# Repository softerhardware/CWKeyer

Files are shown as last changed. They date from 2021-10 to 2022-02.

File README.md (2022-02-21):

# CW Keyer for the Hermes-Lite and other SDR software

This project is a CW keyer for amateur radio. The hardware connects to a PC with USB. It then appears as an audio device for radio sound output and microphone input. It is also a Midi device to signal key up/down to the PC software, and a serial device for a connection to logging or other software on the PC. It is designed for the [Hermes-Lite 2.0](http://www.hermeslite.com/) or other SDR software. The radio sound is sent to the keyer and the keyer generates a sidetone, mixes it with the audio and sends it to the headphones or speaker. The sidetone has zero delay and is suitable for high speed CW. The keyer can also be used with a regular analog radio by using the key and PTT outputs. This project is currently a DIY project with instructions below for those who feel comfortable with some light soldering and Arduino programming.

## Hardware

The hardware consists of a carrier board as shown below and a [Teensy 4](https://www.pjrc.com/teensy/) microcontroller.
The Teensy can be purchased from [Teensy](https://www.pjrc.com/store/teensy40.html) or from [sparkfun](https://www.sparkfun.com/), [adafruit](https://www.adafruit.com/), [mouser](https://www.mouser.com/), [digikey](https://www.digikey.com/) or [amazon](https://www.amazon.com/). Make sure to order the Teensy 4.

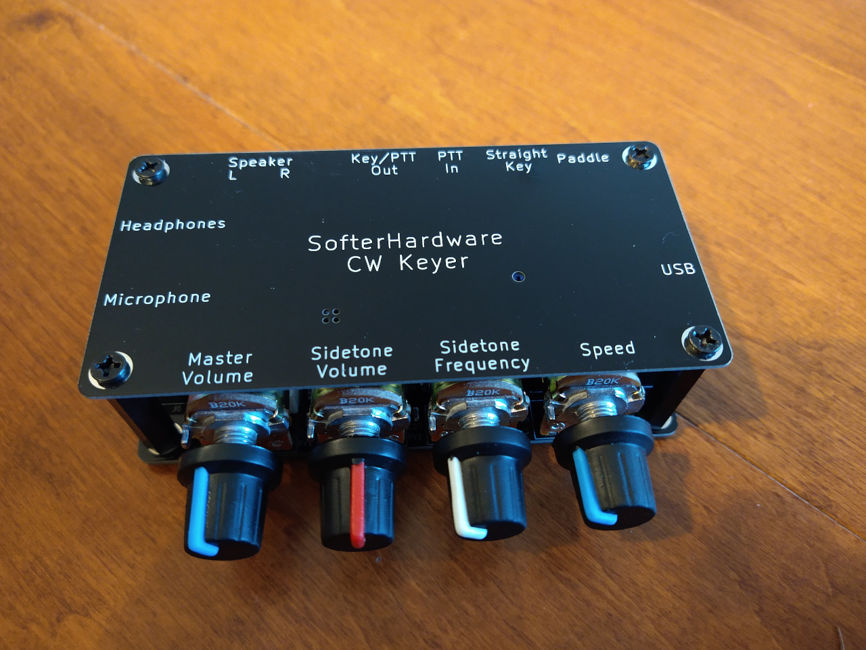
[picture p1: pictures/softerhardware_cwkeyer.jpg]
SofterHardwareCWKeyer


## Software

Keyer software must be loaded into the Teensy 4 microcontroller. The Teensy 4 is programmed via a usb connection to a host computer. First, download and install the Teensy loader application for your operating system as described on [this page](https://www.pjrc.com/teensy/loader.html). Then start the teensy application. Press the programming button on the Teensy and the teensy app will change to show a picture of the board. Then select the ".hex" program file, select "program" and then "reboot".

There are currently two keyer programs available, the "hasak" and the "TeensyWinkeyEmulator". Click on the "firmware" link above, and click through the directories until you find the hex file you want. The file will appear as a table of numbers with a "Raw" button on the upper right side. Right click the Raw button and select "Save link as". Make sure the file name ends in ".hex". Save the hex file and use it to program the Teensy.

## Ctrlr

TBD: Basic description, download and use instructions for Ctrlr MIDI control panel.

## Software Development

To write your own keyer software or to contribute to software development first clone this repository.
This git repository uses several submodules to collect various projects into a single repository. You must initialize submodules when intially cloning:

git clone --recurse-submodules git@github.com:softerhardware/CWKeyer.git

After that, also be sure to pull updates from submodules:

git pull --recurse-submodules

You can find more details about how to work with git submodules on the internet.

### Teensy Libraries

Current development is done using [Arduino IDE 1.8.19](https://www.arduino.cc/en/software) and [Teensyduino 1.56](https://www.pjrc.com/teensy/td_download.html). Please make sure those are installed.

Updated libraries are required for glitchless 48kHz audio with the CW keyer hardware. These libraries are provided in this git repository. An easy way to use these libraries is to add symbolic links to the new libraries from the arduino IDE install. This is described below for Linux and MacOS systems.

Be sure to select the "Teensy 4.0" board in the Tools-->Boards-->Teensiduino menu, and to select the "Serial + Midi + Audio" USB model in the Tools-->USB type menu,
otherwise compilation will fail.

Install teensy  library update for linux:
-----------------------------------------

 1. cd arduino-1.8.19/hardware/teensy/avr
 2. rm -rf cores   (This must be removed or moved outside of the arduino-1.8.19 area otherwise arduino will still pickup this code)
 3. ln -s /home/shaynal/CWKeyer/libraries/teensy/cores .   (Substitute the path for your local git pull of the CWKeyer repository)
 4. cd libraries
 5. rm -rf Audio   (See step 2 comments)
 6. ln -s /home/shaynal/CWKeyer/libraries/teensy/Audio .   (See step 3 comments)
 7. ln -s /home/shaynal/CWKeyer/libraries/teensy/CWKeyerShield .   (See step 3 comments)

Install teensy library update for MacOS:
----------------------------------------

(Added by DL1YCF. Note this is best done from the "terminal" app, then this is very similar to the
linux case).

All the libraries are inside the Teensyduino "app" file bundle (which is a directory tree)
/Applications/Teensyduino.app. Locate a sub-folder called "Audio", this will point you to
the libraries for the Teensy. Normally this is located in

/Applications/Teensyduino.app/Contents/Java/hardware/teensy/avr/libraries

You can copy the "Audio" folder within that folder to a safe place (or just delete it),
and do the same to the "cores" folder one step higher, that is, the "cores" folder within

/Applications/Teensyduino.app/Contents/Java/hardware/teensy/avr

Then proceed as in the linux case, that is, add a symbolic link named "cores" in the .../teensy/avr
folder and two symbolic links called "Audio" and "CWKeyerShield" in the
.../teensy/avr/libraries folder, that point to the directories "Audio", "cores" and
"CWKeyerShield" where you have placed them after down-loading from this repository.

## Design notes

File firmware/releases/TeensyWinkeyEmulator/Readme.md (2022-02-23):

Releases/TeensyWinkeyEmulator
=============================

This directory contains two pre-compiled versions of the TeensyWinkeyEmulator,
one running with the "KeyerShield" (featuring a WM8960 audio codec), the other
for a "SGTL5000 prototype" that is a Teensy 4.0 attached to the "official"
Teensy4 AudioShield (that has a SGTL-5000 codec).

The "prototype" is "keyer only", that is, no Microphone/PTT input, and only
a single potentiometer for changing the CW speed. It has inputs for straight
key and paddle, and an output for the headphone.

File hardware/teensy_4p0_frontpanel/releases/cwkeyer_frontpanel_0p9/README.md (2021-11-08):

CW Keyer Front Panel 0.9 Release
====================

November 7, 2021. This directory contains all files necessary to fabricate the SofterHardware CW Keyer front panel for the Teensy 4.0.

# Files

 * pcb/* - Gerber files names as requested by assembly house

# Changes

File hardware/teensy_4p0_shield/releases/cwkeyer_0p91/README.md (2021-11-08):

CW Keyer 0.9 Release
====================

November 7, 2021. This directory contains all files necessary to fabricate the SofterHardware CW Keyer shield for the Teensy 4.0.

# Files

 * bom/ibom.html - Interactive BOM to help with DIY assembly, open with "firefox ibom.html"
 * cwkeyer.xlsx - BOM type and organization as requested by assembly house
 * cwkeyer.pdf - Schematic for this release
 * pcb/* - Gerber files names as requested by assembly house
 * position/* - Position information to aid assembly, not guaranteed to be accurate for parts with more than two pins
 * stencil/* - Top and bottom stencils for stencil creation guidance

# Changes

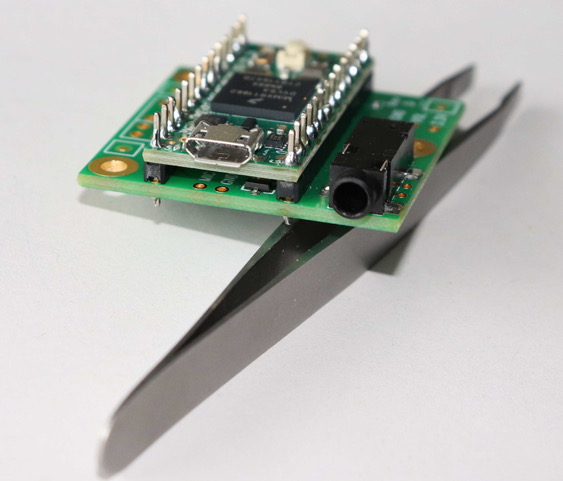
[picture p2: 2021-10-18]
pictures/dl1ycf.jpg

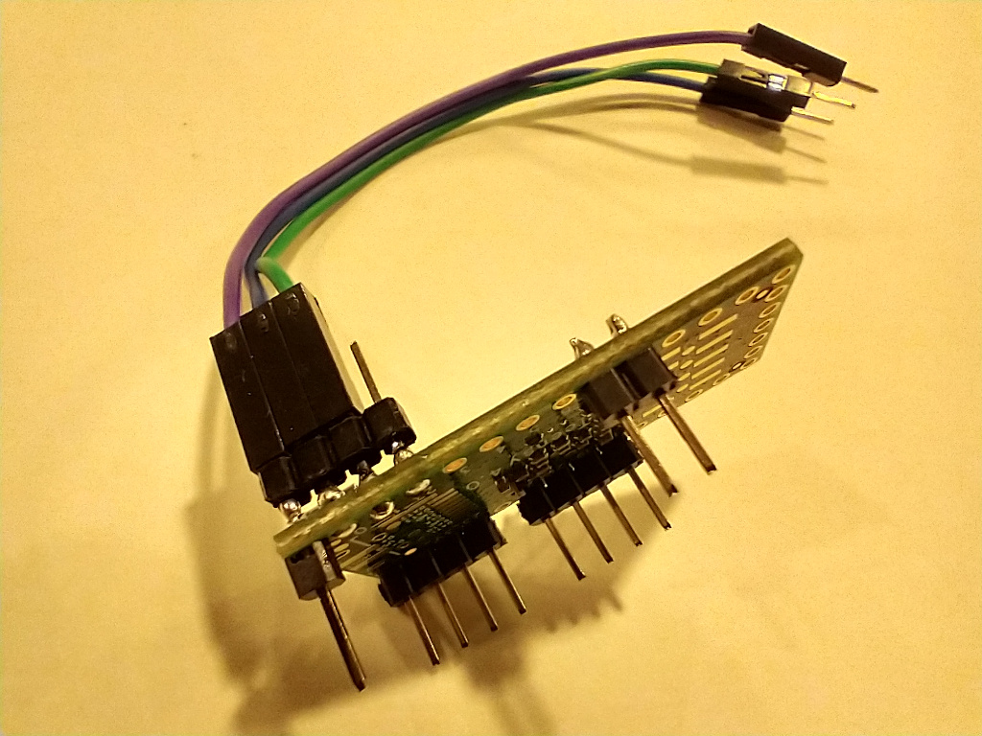
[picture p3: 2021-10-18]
pictures/teensy4.jpg

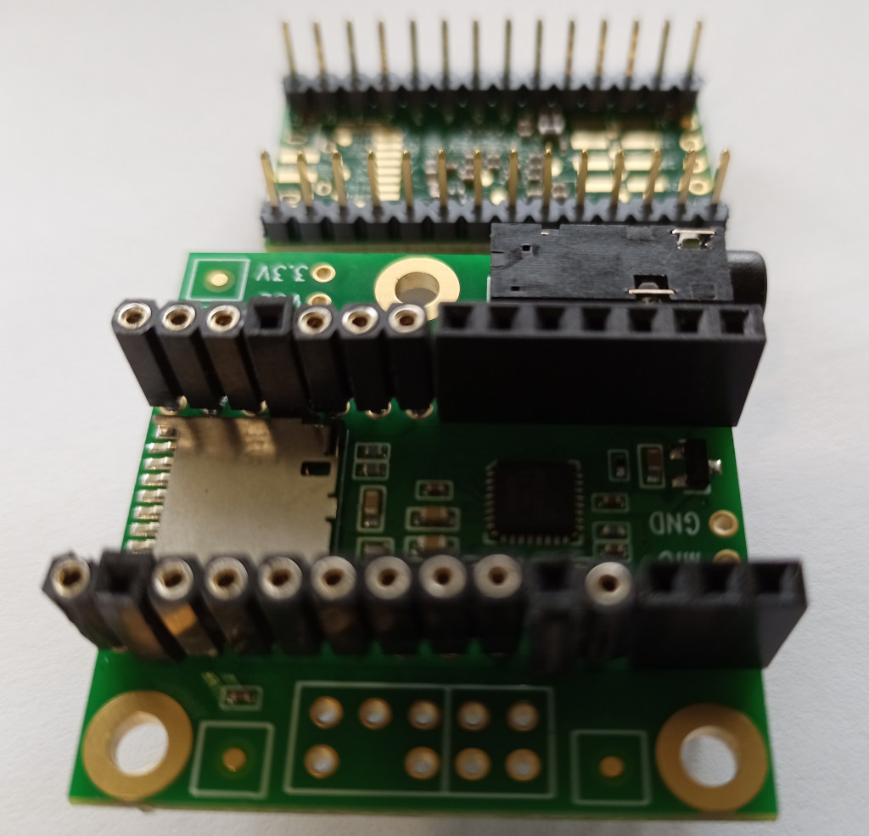
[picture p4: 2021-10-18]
pictures/Shield_Top.jpg

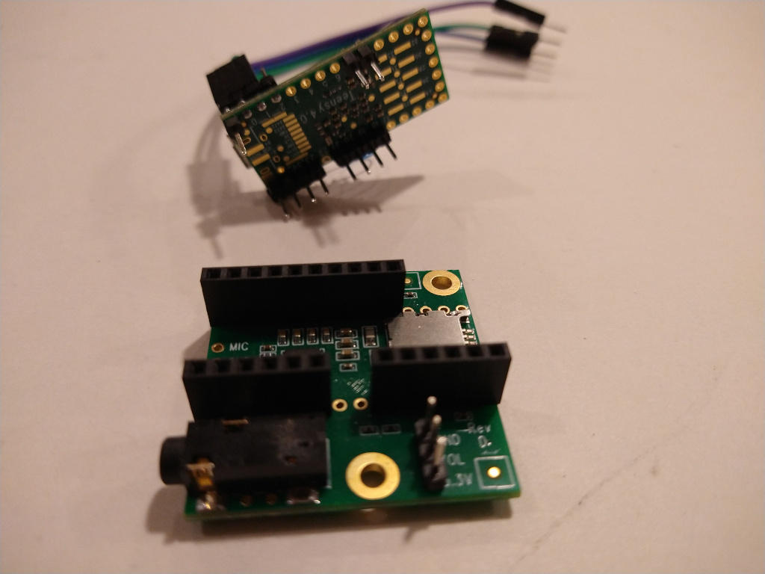
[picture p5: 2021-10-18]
pictures/audioshield.jpg

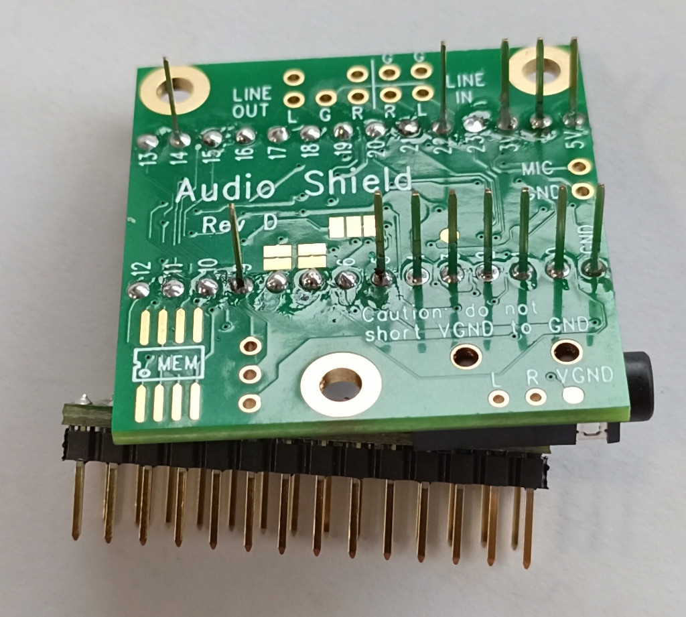
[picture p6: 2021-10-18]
pictures/Shield_Under.jpg

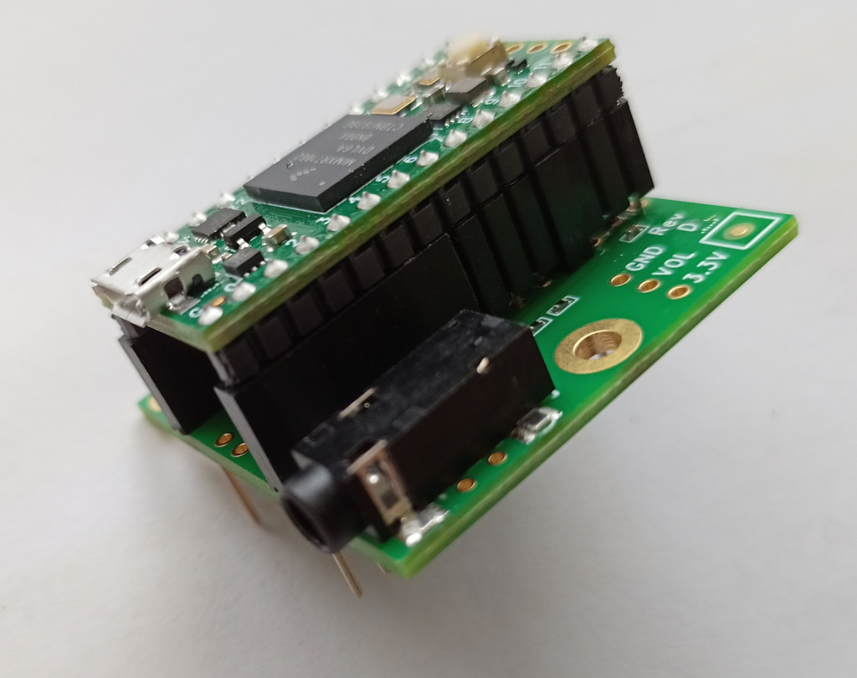
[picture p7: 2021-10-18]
pictures/Plugged_together.jpg

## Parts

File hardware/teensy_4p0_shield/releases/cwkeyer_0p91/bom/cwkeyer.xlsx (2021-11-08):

Line | Designators | Value | Specification | Footprint | Substitution Allowed | LCSC | Quantity | SMT Pins | TH Pins | Notes
1 | C1, C6, C7, C8, C12, C22, C34 | 47uF | >=10V >=X5R <=20% | 1206 | Y | C96123 | 7 | 14
2 | C2, C3, C4, C5, C10, C25, C26, C27, C28, C33, C35 | 0.1uF | >=25V >=X5R <=20% | 603 | Y | C14663 | 11 | 22
3 | C9, C11, C15 | 1uF | >=25V >=X5R <=20% | 603 | Y | C15849 | 3 | 6
4 | C13, C14, C18, C19, C20, C21, C23, C24, C36, C37, C38, C39 | 33pF | >=25V >=X5R <=20% | 603 | Y | C1663 | 12 | 24
5 | C16, C17 | 470nF | >=25V >=X5R <=20% | 603 | Y | C1623 | 2 | 4
6 | C29, C30, C31, C32 | 10nF | >=25V >=X5R <=20% | 603 | Y | C57112 | 4 | 8
7 | D1 | SP0503BAHTG | TVS Diode | SOT-143 | N | C2682275 | 1 | 2
8 | FB1, FB2, FB3, FB4, FB5, FB6, FB7, FB8, FB10, FB11, FB12, FB13 | Ferrite Bead | >=500mA >=100Ohm@100MHz <=200mOhm@DC | 603 | Y | C76892 | 12 | 24
9 | J1, J2, J3, J4 | 2.5mm 2x1 Male | XH-2A |  | Y | C20079 | 4 |  | 8
10 | J5, J6, J7, J8, J9, J12 | Stereo Audio Jack | PJ-307C |  | Y | C16684 | 6 |  | 30
11 | J10 | 2.0mm 4x1 Male | PH-4A |  | Y | C2321 | 1 |  | 4
12 | J11 | 2.54mm 2x5 Male | 2.54mm common header |  | Y | C492422 | 1 |  | 10
13 | JP1 | 2.54mm 2x3 Male | 2.54mm common header |  | Y | C65114 | 1 |  | 6
14 | L1, L2, L3, L4 | 15uH | >=600mA <=600mOhm <=20% | 1210 | Y | C883545 | 4 | 8
15 | L5 | BLM18BD252SN1 | >=150mA >=2.5K@100MHz <=1.5Ohm@DC | 603 | Y | C77668 | 1 | 2
16 | MIC1 | 5A0-3729-M-42-008 | MEMS Microphone |  | N |  | 1 | 4 |  | Seeed Studio Shenzhen Guang Ji Xing Electronic Co
17 | R1, R2 | 4.7K | 1/10W <=5% | 603 | Y | C23162 | 2 | 4
18 | R3, R6, R7 | 47K | 1/10W <=5% | 603 | Y | C25819 | 3 | 6
19 | R4 | 33Ohm | 1/10W <=5% | 603 | Y | C23140 | 1 | 2
20 | R5 | 680Ohm | 1/10W <=5% | 603 | Y | C23228 | 1 | 2
21 | R10, R11, R14 | 470Ohm | 1/10W <=5% | 603 | Y | C23179 | 3 | 6
22 | RV1, RV2, RV3, RV4 | 20K Linear Taper Pot | 15mm shaft, 3 pin 5mm spacing |  | Y |  | 4 |  | 12 | https://www.aliexpress.com/item/1005002229102727.html
23 | U1 | WM8960 | Audio Codec | QFN-32 | N | C18752 | 1 | 32
24 | U2 | MOCD217R2M | OptoCoupler | SO-8_3.9mm | N | C14315 | 1 | 8
25 | U3 | 2.54mm 1x14 Socket | 2044-1X14G00SA |  | Y |  | 2 |  | 28 | Install two female sockets User to install Teensy 4.0 Digi-Key similar part 2553-2044-1X14G00SA-ND
 |  |  |  |  |  |  | 89 | 178 | 98 | Totals
Do Not Assemble:
R8, R9, R12, R13

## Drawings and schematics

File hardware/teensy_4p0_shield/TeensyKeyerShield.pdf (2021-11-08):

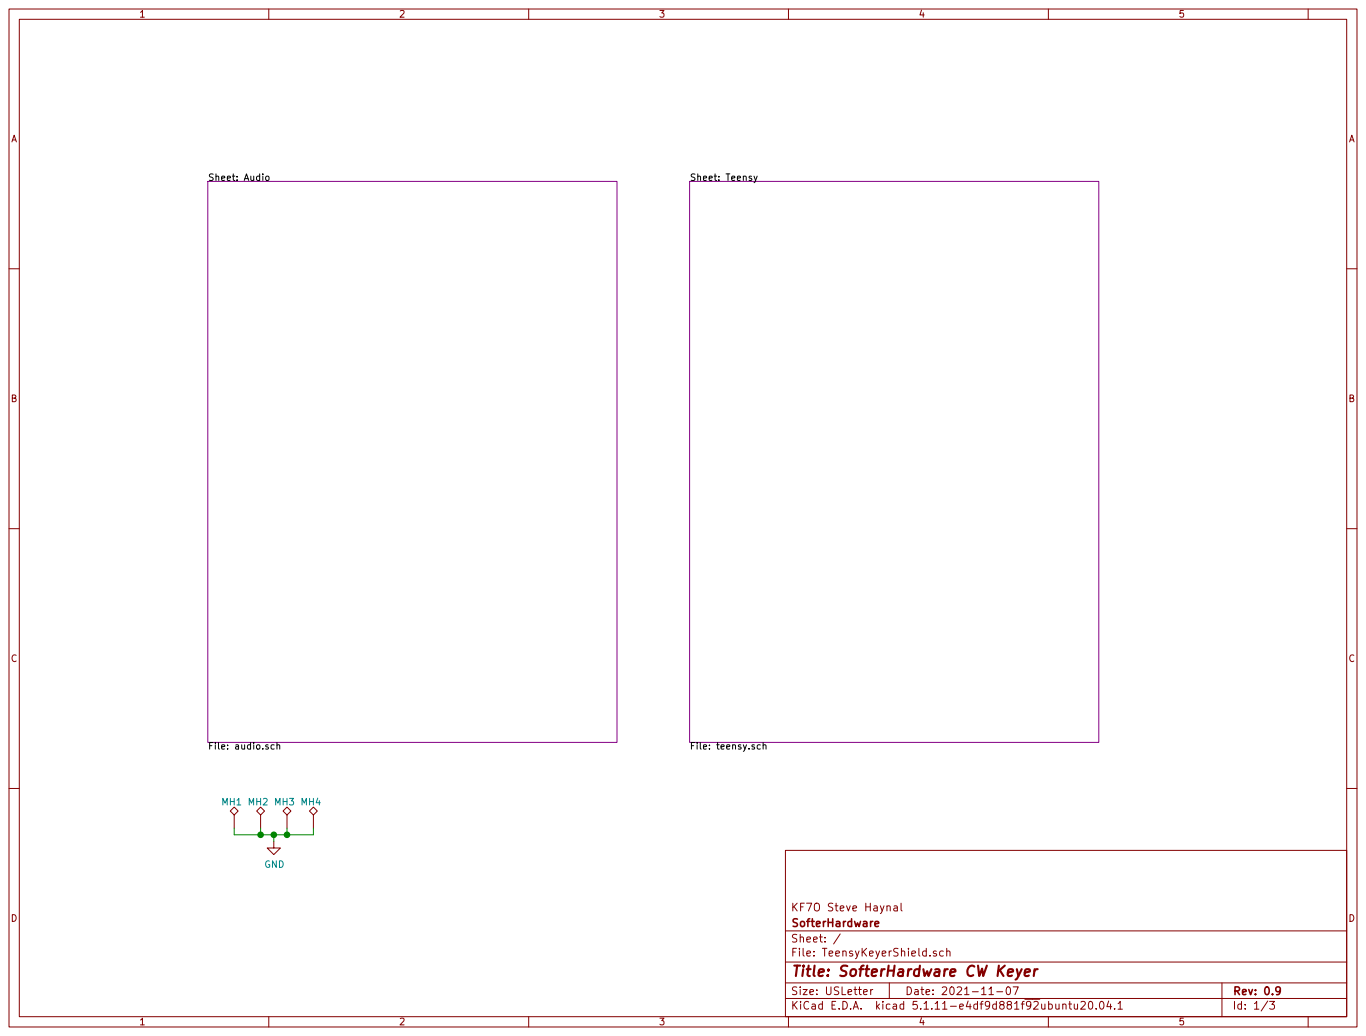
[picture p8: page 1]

Sheet: Audio File: audio.sch MH1 MH2 MH3 MH4 GND

File: TeensyKeyerShield.sch Sheet: / SofterHardware KF7O Steve Haynal

Id: 1/3 Title: SofterHardware CW Keyer

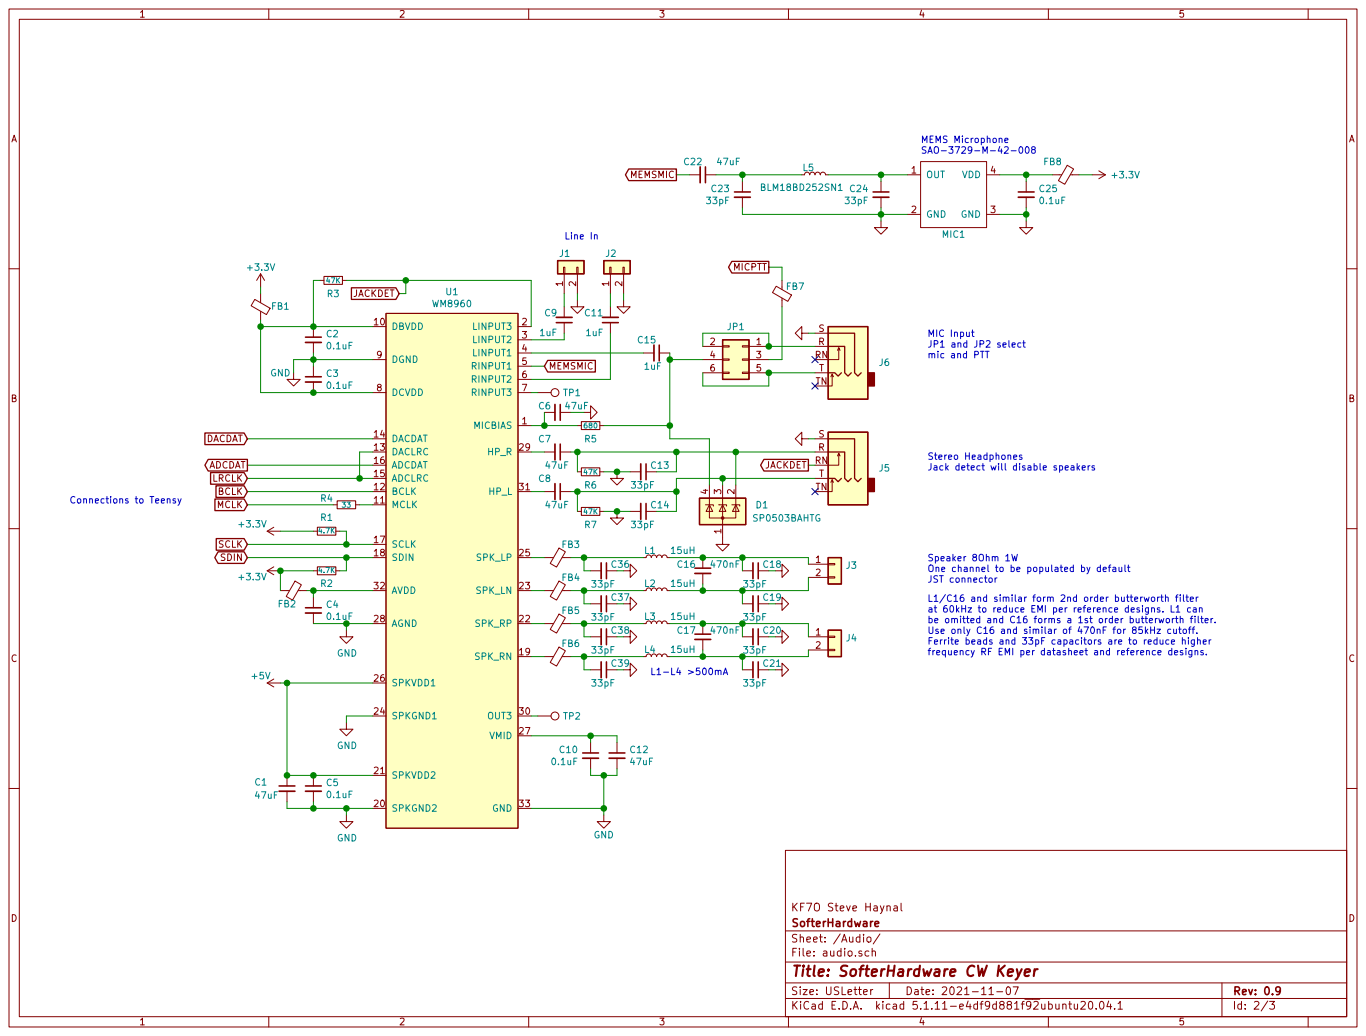
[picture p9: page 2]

MIC Input JP1 and JP2 select mic and PTT MEMS Microphone SAO-3729-M-42-008

One channel to be populated by default JST connector Stereo Headphones
Jack detect will disable speakers

L1/C16 and similar form 2nd order butterworth filter at 60kHz to reduce EMI per reference designs. L1 can

be omitted and C16 forms a 1st order butterworth filter. Use only C16 and similar of 470nF for 85kHz cutoff.

Ferrite beads and 33pF capacitors are to reduce higher
frequency RF EMI per datasheet and reference designs.

Id: 2/3 Title: SofterHardware CW Keyer File: audio.sch Sheet: /Audio/ SofterHardware KF7O Steve Haynal

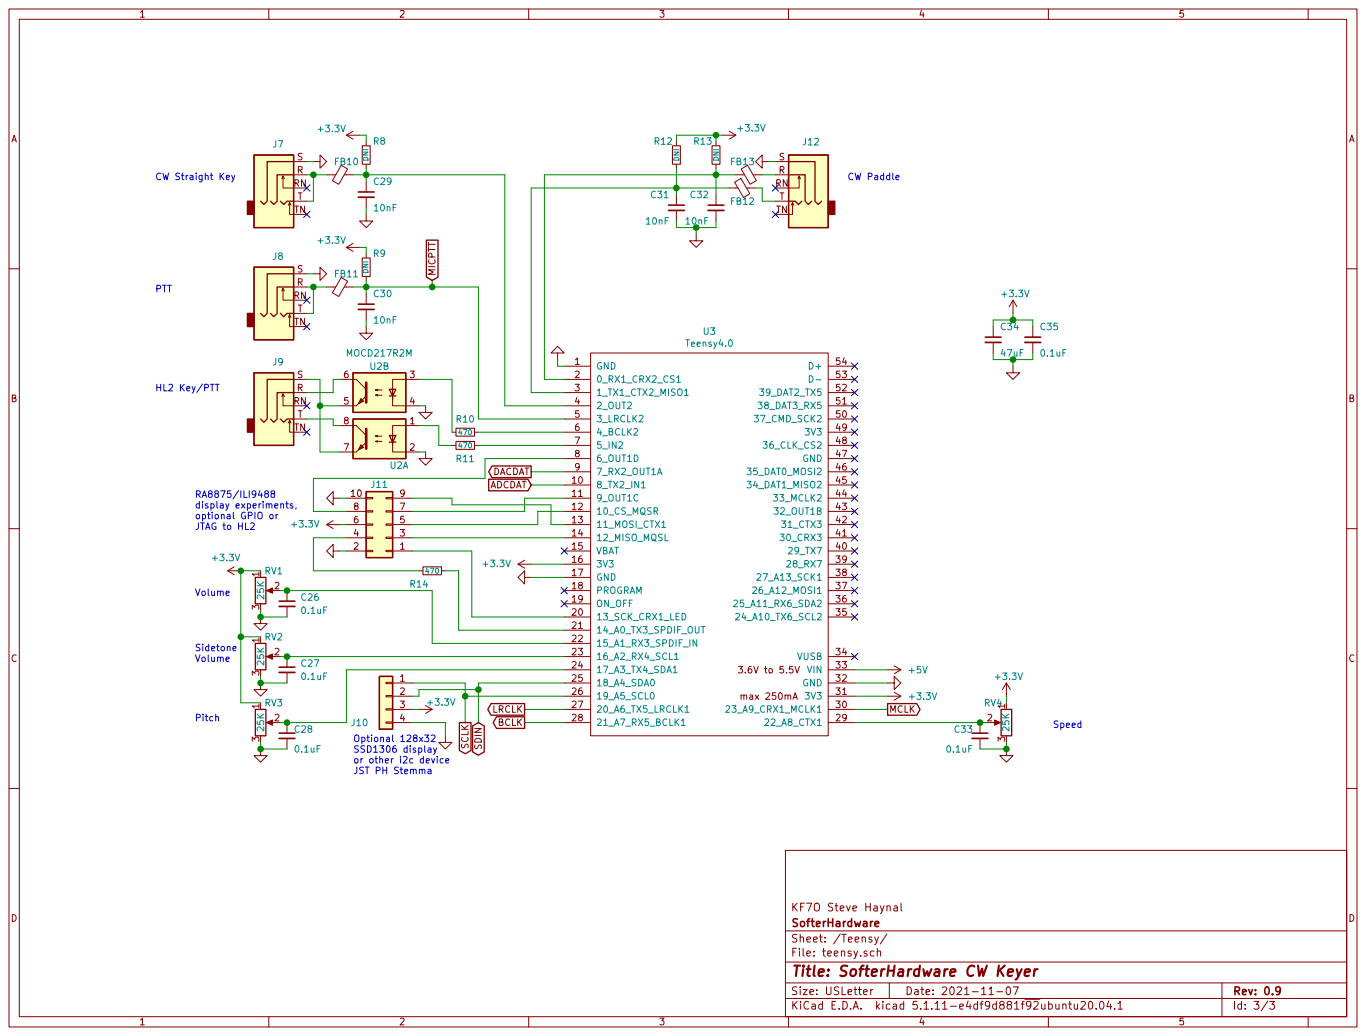
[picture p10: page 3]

JST PH Stemma RA8875/ILI9488
display experiments,
optional GPIO or JTAG to HL2

18_A4_SDA0 25

20_A6_TX5_LRCLK1 27

Optional 128x32
SSD1306 display or other i2c device

Sheet: /Teensy/ SofterHardware KF7O Steve Haynal

File: teensy.sch
Id: 3/3 Title: SofterHardware CW Keyer

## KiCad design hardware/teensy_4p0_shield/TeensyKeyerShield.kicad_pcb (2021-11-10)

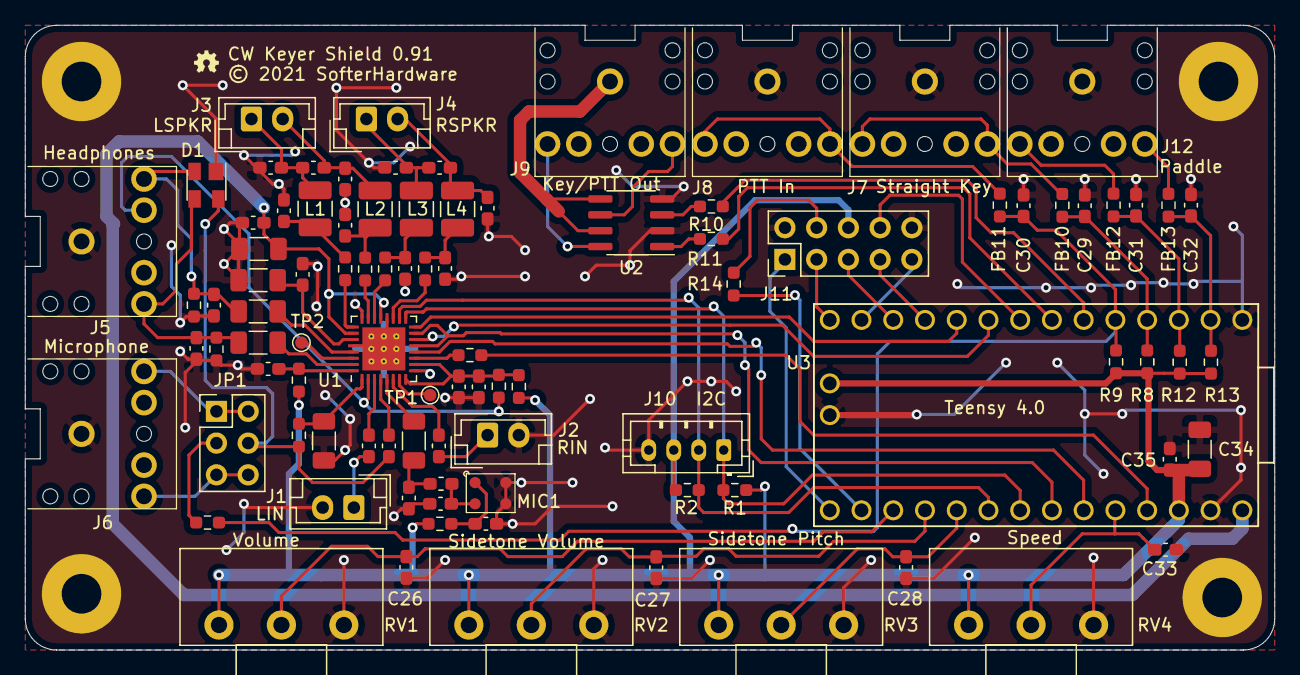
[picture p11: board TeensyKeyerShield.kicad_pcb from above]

Board: 2 copper layers, 100.0 x 50.0 mm, 98 parts (0 on the bottom side), 74 nets.

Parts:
C1, C6, C7, C8, C12, C22, C34: 47uF; C_1206_3216Metric_Pad1.33x1.80mm_HandSolder
C2, C3, C4, C5, C10, C25, C26, C27, C28, C33, C35: 0.1uF; C_0603_1608Metric_Pad1.08x0.95mm_HandSolder
C9, C11, C15: 1uF; C_0603_1608Metric_Pad1.08x0.95mm_HandSolder
C13, C14, C18, C19, C20, C21, C23, C24, C36, C37, C38, C39: 33pF; C_0603_1608Metric_Pad1.08x0.95mm_HandSolder
C16, C17: 470nF; C_0603_1608Metric_Pad1.08x0.95mm_HandSolder
C29, C30, C31, C32: 10nF; C_0603_1608Metric_Pad1.08x0.95mm_HandSolder
D1: SP0503BAHTG; SOT-143
FB1, FB2, FB3, FB4, FB5, FB6, FB7, FB8, FB10, FB11, FB12, FB13: Ferrite_Bead_Small; R_0603_1608Metric_Pad0.98x0.95mm_HandSolder
J1, J2, J3, J4: Conn_01x02; JST_EH_B2B-EH-A_1x02_P2.50mm_Vertical
J5, J6, J7, J8, J9, J12: AudioJack3_SwitchTR; STEREO_TRS
J10: Conn_01x04; JST_PH_B4B-PH-K_1x04_P2.00mm_Vertical
J11: Conn_02x05_Odd_Even; PinHeader_2x05_P2.54mm_Vertical
JP1: Conn_02x03_Odd_Even; PinHeader_2x03_P2.54mm_Vertical
L1, L2, L3, L4: 15uH; L_1210_3225Metric_Pad1.42x2.65mm_HandSolder
L5: BLM18BD252SN1; L_0603_1608Metric_Pad1.05x0.95mm_HandSolder
MH1, MH2, MH3, MH4: TestPoint_Alt; MH
MIC1: MEMSMIC
R1, R2: 4.7K; R_0603_1608Metric_Pad0.98x0.95mm_HandSolder
R3, R6, R7: 47K; R_0603_1608Metric_Pad0.98x0.95mm_HandSolder
R4: 33; R_0603_1608Metric_Pad0.98x0.95mm_HandSolder
R5: 680; R_0603_1608Metric_Pad0.98x0.95mm_HandSolder
R8, R9, R12, R13: DNI; R_0603_1608Metric_Pad0.98x0.95mm_HandSolder
R10, R11, R14: 470; R_0603_1608Metric_Pad0.98x0.95mm_HandSolder
RV1, RV2, RV3, RV4: 25K; Potentiometer_Piher_T-16H_Single_Horizontal
TP1, TP2: TestPoint; TestPoint_Pad_D1.0mm
U1: WM8960; QFN-32-1EP_5x5mm_P0.5mm_EP3.45x3.45mm_ThermalVias
U2: MOCD217R2M; SOIC-8_3.9x4.9mm_P1.27mm
U3: Teensy4.0; Teensy40

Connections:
+3V3: C34.1, C35.1, FB1.2, FB2.2, FB8.1, J10.3, J11.6, R1.1, R2.1, R8.2, R9.2, R12.2, R13.2, RV1.1, RV2.1, RV3.1, RV4.1, U3.16, U3.31
+5V: C1.1, C5.1, U1.21, U1.26, U3.33
ADCDAT: U1.16, U3.10
BCLK: U1.12, U3.28
DACDAT: U1.14, U3.9
GND: C1.2, C2.2, C3.1, C4.2, C5.2, C6.1, C10.2, C12.2, C13.2, C14.2, C18.1, C19.1, C20.1, C21.1, C23.2, C24.2, C25.2, C26.2, C27.2, C28.2, C29.2, C30.2, C31.2, C32.2, C33.2, C34.2, C35.2, C36.1, C37.1, C38.1, C39.1, D1.1, J1.2, J2.2, J5.S, J6.S, J7.S, J8.S, J10.4, J11.2, J11.10, J12.S, MH1.1, MH2.1, MH3.1, MH4.1, MIC1.2, MIC1.3, R6.1, R7.1, RV1.3, RV2.3, RV3.3, RV4.3, U1.9, U1.20, U1.24, U1.28, U1.33, U2.2, U2.4, U3.1, U3.17, U3.32
JACKDET: J5.RN, R3.1, U1.2
LRCLK: U1.13, U1.15, U3.27
MCLK: R4.2, U3.30
MEMSMIC: C22.2, U1.5
MICPTT: C30.1, FB7.2, FB11.1, R9.1, U3.5
unnamed: C2.1, C3.2, FB1.1, R3.2, U1.8, U1.10
unnamed: C4.1, FB2.1, U1.32
unnamed: C6.2, R5.2, U1.1
unnamed: C7.2, U1.29
unnamed: C8.2, U1.31
unnamed: C9.1, U1.3
unnamed: C9.2, J1.1
unnamed: C10.1, C12.1, U1.27
unnamed: C11.1, U1.6
unnamed: C11.2, J2.1
unnamed: C7.1, C13.1, D1.2, J5.R, R6.2
unnamed: C8.1, C14.1, D1.3, J5.T, R7.2
unnamed: C15.1, D1.4, JP1.4, R5.1
unnamed: C15.2, U1.4
unnamed: C16.1, C18.2, J3.1, L1.2
unnamed: C16.2, C19.2, J3.2, L2.2
unnamed: C17.1, C20.2, J4.1, L3.2
unnamed: C17.2, C21.2, J4.2, L4.2
unnamed: C22.1, C23.1, L5.1
unnamed: C24.1, L5.2, MIC1.4
unnamed: C25.1, FB8.2, MIC1.1
unnamed: C26.1, RV1.2, U3.22
unnamed: C27.1, RV2.2, U3.23
unnamed: C28.1, RV3.2, U3.24
unnamed: C29.1, FB10.1, R8.1, U3.4
unnamed: C31.1, FB12.1, R12.1, U3.3
unnamed: C32.1, FB13.1, R13.1, U3.2
unnamed: C33.1, RV4.2, U3.29
unnamed: C36.2, FB3.1, L1.1
unnamed: C37.2, FB4.1, L2.1
unnamed: C38.2, FB5.1, L3.1
unnamed: C39.2, FB6.1, L4.1
unnamed: FB3.2, U1.25
unnamed: FB4.2, U1.23
unnamed: FB5.2, U1.22
unnamed: FB6.2, U1.19
unnamed: FB7.1, JP1.3
unnamed: FB10.2, J7.R, J7.T
unnamed: FB11.2, J8.R, J8.T
unnamed: FB12.2, J12.T
unnamed: FB13.2, J12.R
unnamed: J6.R, JP1.1, JP1.2
unnamed: J6.T, JP1.5, JP1.6
unnamed: J9.R, U2.6
unnamed: J9.S, U2.5, U2.7
unnamed: J9.T, U2.8
unnamed: J11.1, U3.20
unnamed: J11.3, U3.14
unnamed: J11.4, R14.2
unnamed: J11.5, U3.12
unnamed: J11.7, U3.11
unnamed: J11.8, U3.8
unnamed: J11.9, U3.13
unnamed: R4.1, U1.11
unnamed: R10.1, U3.6
unnamed: R10.2, U2.3
unnamed: R11.1, U3.7
unnamed: R11.2, U2.1
unnamed: R14.1, U3.21
unnamed: TP1.1, U1.7
unnamed: TP2.1, U1.30
SCLK: J10.1, R1.2, U1.17, U3.26
SDIN: J10.2, R2.2, U1.18, U3.25

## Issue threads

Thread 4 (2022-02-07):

Standardize JST Connector

softerhardware, 2022-02-07:
The PCB is meant to use JST PH connectors for line in and speaker out:
https://www.adafruit.com/product/261

The part used by Makerfabs and/or specified in the BOM doesn't match the above connector. There is a connector and SMT overlap at one place on the PCB.

Review and update the PCB and/or BOM so that JST PH connectors can be used.

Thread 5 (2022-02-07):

Finalize MIC Biasing

softerhardware, 2022-02-07:
The mic biasing used is based on the reform laptop:
https://www.crowdsupply.com/mnt/reform

The bias is applied to the tip and not the ring. This may not work with all microphones.

Test with various microphones and change or update the bias so that it works with as wide a range of microphones as easily possible.

dl1ycf, 2022-02-14:
Well, depends what you want. If you provide "mic and bias" both on the tip, you have the ring free for PTT. If you provide mic and bias on on tip+ring you have to use two plugs for the microphone (the second one going to the PTT jack). So at least via jumpering, it should be possible to have Mic+Bias tied  together on one contact (ring or tip) and PTT on the other.

P.S.: would be nice if one could remove the bias via jumpers. No problem for me since I have a decoupling cap, but I use a dynamical mic with built-in battery-driven preamp  and this would not like the bias if there were no decoupler.

Bottom line: if  you want to be everybody's Darling, perhaps the mic connector must have a graveyard of jumpers.

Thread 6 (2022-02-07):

Make POTs Optional or Provide More Support

softerhardware, 2022-02-07:
The current pots are bulky and not well mechanically supported.

One option is to make the POTs optional, and require a user to adjust all settings via software.

Another option is to keep the POTs but provide more mechanical support.
a) Create a small PCB that is a faceplate for the POTs. This will gang all POTs together, and can attach to the front posts.
b) Create a small PCB that is parallel to the top and bottom PCBs but fits over the four POTS (rectangular openings for the large vertically-veiwed portions of the POTS). This gangs the 4 POTs together with a smaller PCB than option a.
c) 3D printed solutions.

recri, 2022-02-07:
I still favor a minimal footprint, codec+optoisolators and miscellaneous C and R and FB with pads for soldering jacks on short leads.  A squid.  Strain relief by zip tying the cables to the PCB in a short serpentine.  Bring out the unused digital and analog pins to pads (or just wire wrap or solder to the Teensy pins or pads) and it's easy to add pots, button arrays on a resistor ladder, rotary encoder, oled displays, or whatever.  Pads for line in, line out, headphones, speakers, microphone, straight key, paddle, external ptt, key out, ptt out, ... .  The size of a Teensy 4.1.  Default package in heat shrink tubing.

mi0bot, 2022-02-14:
I know that you are going to do another revision of the PCB. Would it be worth considering using encoders instead of pots or would that be to big a change?

dl1ycf, 2022-02-15:
I am not good at mechanical engineering, but the file shows what I plan

[Keyer.pdf](https://github.com/softerhardware/CWKeyer/files/8073381/Keyer.pdf)

A 100*82 mm aluminum piece (1 or 1.5 mm thick) is bended such that there is a 100*50 mm horizontal base and a 100*32mm upright piece. The upright piece gets four large holes for the pots, and the horizontal piece gets four small holes for the screws.  These screw go through the aluminum, through 2mm isolating rings into the "posts" that hold the
keyer upper and lower plate. Not really fancy, but possible even for me to make.

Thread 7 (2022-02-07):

Teensy Audio Locks-up, multiple devices detected

softerhardware, 2022-02-07:
There have been reports of the teensy USB audio device locking up when used with other USB audio devices on dell computers.

There have been reports of multiple teensy USB audio devices showing up when only one is expected.

mi0bot, 2022-02-14:
The CM6206 chip set was in the USB sound card that was causing the problem with the Teensy sound interface. I bought another USB sound card using the CM108 chip set and the issue has gone away.

The problem was only with Dell Precision M4700 and M6500 laptops. I tried the two problem sound cards on HP and Lenovo laptops and they didn't have the same issue.

K7MDL2, 2023-02-04:
I can run USB audio+dual serial on my Teensy SDR project for days no problem.  It *does* lockup randomly and often if I also use the Teensy USB Host port. The USB Host port is unaffected by the lockups.  In my Teensy Keyer embedded in my PiHPSDR controller it occasionally stops talking.  I have no idea why or how often as I use this system sporadically.

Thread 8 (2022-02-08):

should midi control change 6 be avoided?

ahopper, 2022-02-08:
Should cc addresses 6,38,98 & 99 be reserved for nrpn messages? 6 is currently used for MIDI_SIDETONE_FREQUENCY which could complicate use of nrpn later.

Closed 2022-02-12.

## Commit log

2021-10-26 TeensyKeyerShield floorplanning
    [TeensyKeyerShield.kicad_pcb, TeensyKeyerShield.sch, audio.sch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]
2021-10-29 Updated with some routing
    [TeensyKeyerShield.kicad_pcb]
2021-11-01 Most routing done
    [TeensyKeyerShield.kicad_pcb, audio.sch, teensy.sch]
2021-11-04 Mostly done with routing and silkscreen
    [TeensyKeyerShield.kicad_pcb, TeensyKeyerShield.sch, audio.sch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]
2021-11-06 Added ibom.html
    [TeensyKeyerShield.kicad_pcb, TeensyKeyerShield.sch, audio.sch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]
2021-11-08 Release 0p9
    [cwkeyer.xlsx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]
2021-11-08 Add frontpanel
    [TeensyKeyerFrontPanel.kicad_pcb, TeensyKeyerFrontPanel.sch, TeensyKeyerShield.kicad_pcb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]
2021-11-10 0p91 shield release
    [TeensyKeyerShield.kicad_pcb, TeensyKeyerShield.sch, audio.sch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]
2022-01-03 New commits to TeensyWinkeyEmulator and k3ng_cw_keyer submodules
2022-01-09 Updates to TeensyWinkeyEmulator and Audio
2022-01-10 Change path to TeensyWinkeyEmulator
2022-01-10 Updated readme and TeensyWinkeyEmulator .hex file
2022-01-14 Updates to hasak and TeensyWinkeyEmulator, added cwkeyer.py
2022-01-25 Update README.md
    Updated instructions (Boards and USB type menu).
2022-01-31 Pulled TeensyWinkeyEmulator updates
2022-01-31 a) Improved handling of Pots. Speed pot now has larger "delta v/delta phi" for large speeds. b) PTT and CW-key handling now in "Shield" module c) Initialized microphone input d) handling of PTT now f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
2022-02-03 Pulled in TeensyWinkeyEmulator updates
2022-02-03 Updating to current hasak origin main.
2022-02-08 advances to latest commit of TeensyWinkeyEmulator
2022-02-12 Cleaned up compile time errors and tested on TeensyWinkeyEmulator.
2022-02-13 New hex file for TeensyWinkeyEmulator
2022-02-14 latest pull of the TeensyWinkeyEmulator
2022-02-14 updated TeensyWinkeyEmulator submodule
2022-02-15 pulled latest TeensyWinkeyEmulator commits
2022-02-15 New TeensyWinkeyEmulator hex file.
2022-02-16 pulles latest commit for TeensyWinkeyEmulator
2022-02-16 Created "own" directory for TeensyWinkeyEmulator Release Hex File.
2022-02-17 New pull on TeensyWinKeyEmulator
2022-02-23 new commits for TeensyWinkeyEmulator
2022-02-28 Updated TeensyWinkeyEmulator (should be close to final now)

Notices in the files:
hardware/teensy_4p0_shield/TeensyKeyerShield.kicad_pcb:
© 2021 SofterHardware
